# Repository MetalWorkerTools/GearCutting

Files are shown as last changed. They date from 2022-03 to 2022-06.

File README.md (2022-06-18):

## Making gear cutters and (helical) gears using the button method.
A video, 3D design and excel calculation sheet for making gear cutters and (helical) gears on the mill and on the lathe using the button method.
### Video:
A [YouTube video](https://youtu.be/ImloYwHc-BY) that shows how to make gear cutters and (helical) gears on the mill and on the lathe.
### Calculations:
In the [calculations](https://github.com/MetalWorkerTools/GearCutting) folder there is an excel sheet for the calculations.
### 3D design:
In the [3D design](https://github.com/MetalWorkerTools/GearCutting/tree/main/3D%20design) folder there is the FreeCad CAD file. In this file you find the design of the fly cutter and end mill style cutter.
### 3D print:
In the [3D print](https://github.com/MetalWorkerTools/GearCutting/tree/main/3D%20print) folder is a stf file for printing a plate for testing gears.

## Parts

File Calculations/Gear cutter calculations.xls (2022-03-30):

Gearcutter calculations for using a tapered (cone) drill
 |  |  |  | Only change the blue values
Gear Data |  |  |  | description | Links:
Preasure Angle | p | ° | 20 | 20° is common, 14.5° is rare | Online gear designer
Modul | M |  | 1 | The module of this gear (tooth size) | http://hessmer.org/gears/InvoluteSpurGearBuilder.html
Number of teeth | N |  | 17 | The lowest number of teeth this gearcutter can be used for
 |  |  |  |  | Book Ivan Law: Gears and Gear Cutting
Diametrical Pitch | DP |  | 25.40 | The ratio of the number of teeth per inches and the pitch diameter | https://www.bookdepository.com/Gears-and-Gear-Cutting-Ivan-R.-Law/9780852429112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
Circular Pitch | CP | " | 0.124 | Distance of the arc between 2 corresponding points on a tooth in inch
Circular Pitch | CP | mm | 3.14159 | Distance of the arc between 2 corresponding points on a tooth in mm | Mikes workshop
Pitch Circle Diameter | PD | " | 0.6693 | Pitch Circel Diameter in inch, needed for calculating heart to heart distance between 2 gears | http://mikesworkshop.weebly.com/designing-gear-cutters.html
Pitch Circle Diameter | PDM | mm | 17.00 | Pitch Circle Diameter in mm, needed for calculating heart to heart distance between 2 gears
Tooth thickness | T | " | 0.06 | Thickness of the tooth (arc) on the pitchcircle in inch | John Stevenson who introduced using a tapered drill
Tooth thickness | T | mm | 1.57 | Thickness of the tooth (arc) on the pitchcircle in mm | https://bbs.homeshopmachinist.net/forum/general/43078-a-form-tool-for-gearcutting?t=42051
Chordal Thickness | CT | " | 0.06 | Thickness of the tooth (chord) on the pitchcircle in inch
Chordal Thickness | CT | mm | 1.57 | Thickness of the tooth (chord) on the pitchcircle in mm | Only change the blue values
Gear Cutter Data: fly cutter |  |  |  |  | Cone drill calibration:
Button Diameter | BD | mm | 5.814 | The diameter of the "button" needed to cut this gear
Button Diameter 1/2 | BD | mm | 2.907 | Half of the "button" diameter |  | SheetDrill 1 | SheetDrill 2 | Center Drill 1 | Center Drill 2 | Counter Sink
Button Separation | BS | mm | 6.825 | The heart to heart distance of the 2 buttons to make the gear cutter | Diameter min | 3 | 8 | 5 | 3 | 4 | Not required, just for information
Button Separation 1/2 | BS 0.5 | mm | 3.413 | Half of the button separation | Diameter max | 14 | 20 | 12 | 6 | 13 | Not required, just for information
Infeed | Inf | mm | 2.786 | The infeed of the buttons (reference is the tip of the button) to make the gear cutter. | Angle° | 19.5082666 | 17.0639228 | 60 | 60 | 90
Cutter Width Top | Cwt | mm | 1.016 | The width of the gear cutter tip | Diameter 1 | 5 | 12 | 10 | 5 | 5
Cutter Width Top Adjusted | Cwta | mm | 1.016 | The width of the gear cutter tip, corrected for infeeds larger than the button radius | Height 1 | 6.77 | 15.33 | 9.07 | 6.99 | 1.08
Min Cutter Tool Width | Mctw | mm | 3.142 | The min width of the tool to make the gear cutter, equals the circular pitch | Diameter 2 | 12 | 19.03
 |  |  |  |  | Height 2 | 27.13 | 38.76
Gear Cutter Data: End mill style |  |  |  |  | Taper (mm/mm) | 0.3438113949 | 0.3000426803 | 1.154700538 | 1.154700538 | 2
Cutter Width Top 1/5 |  |  | 0.203 | The width of the flute tip when making an end mill style gearcutter | Factor | 2.908571429 | 3.332859175 | 0.8660254038 | 0.8660254038 | 0.5
Endmill used | Eu | mm | 6.000 | The diameter of the end mill used to mill the tip of the end mill style gear cutter | Offset | -7.772857143 | -24.6643101 | 0.4097459622 | 2.659872981 | -1.42
Infeed Corrected | Infcor | mm | 2.879 | The infeed of the tapered drill when the above end mill was used to mill the tip
 |  |  |  |  | Button Diameter | 5.814 | 5.814 | 5.814 | 5.814 | 5.814
 |  |  |  |  | Heigth | 9.14 | -5.29 | 5.45 | 7.70 | 1.49 | Height=(Factor x Button Diameter) + Offset
Gear Cutting Data
Outside Diameter | OD | " | 0.75 | The diameter of the gear blank in inch
Outside Diameter | OD | mm | 19.00 | The diameter of the gear blank in mm | Test diameter | 5 | 19.03 | 5 | 5 | 5 | For checking calculations
Cutting Depth | D+f | mm | 2.157 | The detph of cut to make a gear using this cutter
Base Diameter | D0 | mm | 15.97 | The base diameter of the gear in mm
Root Diameter | RD | mm | 14.69 | The root diameter of the gear (D-2f) | Height | 6.77 | 38.76 | 4.74 | 6.99 | 1.08
Angular Pitch | Ap | ° | 21.18 | The angle between 2 gear teeth
HSS speed | Vhss | m/min | 150.000 | Aluminium 150,Plastic 120, Brass 60
Feed |  | mm/rev | 0.020 | Feed is an estimation, 2% of cutter tip width
Speed | RPM | /min | 7599.088773 | Hardened silver steel = half the speed for HSS
Feed | V | mm/rev | 231.6638509 | 3 Flute
DP to Modul | DP | 40 | Modul | 0.635

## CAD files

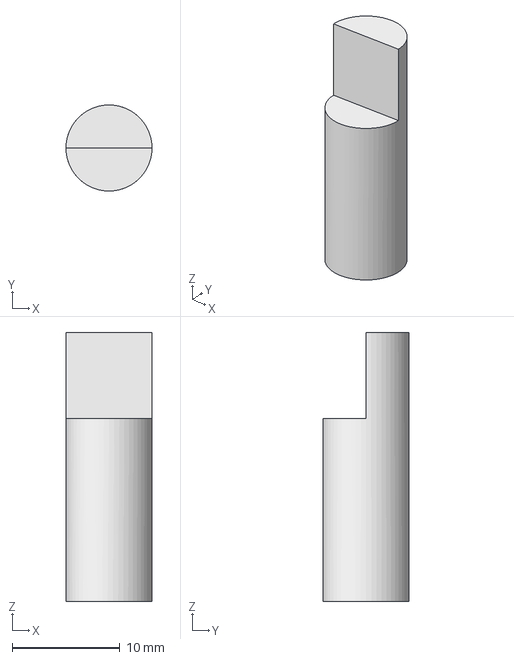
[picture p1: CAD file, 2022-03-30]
3D design/GearCutter.FCStd
8.00 x 8.00 x 25.0 mm

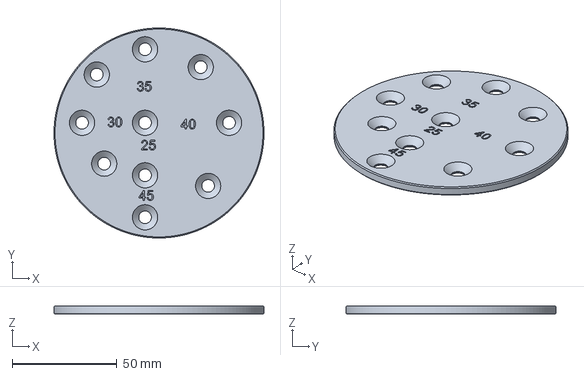
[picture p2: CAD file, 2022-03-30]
3D print/GearTestPlate.3mf
100.0 x 100.0 x 4.00 mm

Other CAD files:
3D design/GearTestPlate.FCStd
3D print/GearTestPlate.stl
